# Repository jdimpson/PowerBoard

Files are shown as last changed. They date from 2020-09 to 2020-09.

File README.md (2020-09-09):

# PowerBoard Redux PCB

These are the Eage CAD Schematics and Board files, plus the Gerbers of some boards as-built, of an AdaFruit PowerBoost 1000C (https://www.adafruit.com/product/2465) adapted to the Raspberry Pi Zero form factor. It provides power to the +5VDC pins of the RPi header (protected via Schottkey diode). As AdaFruit describes the product this is based on, "With a built-in load-sharing battery charger circuit, you'll be able to keep your power-hungry project running even while recharging the battery!"

See also the PowerHolder board (https://github.com/jdimpson/PowerHolder) which is just like this one, but has battery clips to hold a Li Ion 18650 cell on the board, rather than fussing with JST connectors. It also provides a way to use a stock PowerBoost 10000C board so you don't have as much soldering to do.

The board patches the Low Battery (LBO) signal to the Pi via a level shifter, and also adds a programmable tactile button and LED.  You can use either one of those ubiquitous square tactile / momentary buttons, or one that mounts vertically (https://www.digikey.com/product-detail/en/te-connectivity-alcoswitch-switches/1825027-5/450-1662-ND/529484). The footprints for the two buttons overlap, which looks ugly and means you really can choose only one. It also provides a spot for a vertical slide switch that enables or disables the power circuit (https://www.digikey.com/product-detail/en/c-k/OS102011MA1QN1/CKN9559-ND/1981430). It's possible to find horizontal slide switch that fits in the same footprint. (I've only ordered them from ebay.)

Python software that works with the LBO signal, button, and LED are available in the [RPiIoT](https://github.com/jdimpson/RPiIoT) repo.

The MicroUSB connector is not the same foot print as AdaFruit uses in their PowerBoost, because I couldn't figure out which one it was. The part I use is an amphenol 10118194-0001LF (https://www.digikey.com/product-detail/en/amphenol-icc-fci/10118194-0001LF/609-4618-1-ND/2785382). It still has 4 through-hole-ish studs for strength (but can be hot-air reflowed) like AdaFruit's part, but the location of the studs are incompatible.

Battery is connected to a JST-style connector in a manner compatible with how AdaFruit does their polarity, or you can omit the connector and use the 2.54 mm pitch througholes to solder wires or a different connector to. Note that another Repo contains the PowerCarrier board, which is functionally identical to this board, but includes battery holders for a Li-Ion 18650 cell on the board.

Changelog
- Before v1.0 / Redux, I didn't know what I was doing, and kept laying out boards with traces that were way too small for the currents involved. 
- v1.01: Thickened VBAT, VLIPO, and USB traces from circuit to aux header; added zener diode to 5V trace into RPi; using VBAT rather than VLIPO in ENABLE pin switch. 

TODO:
- do over that preserve original PowerBoost footprint so that you can either reflow the board or just pop one of AdaFruit's board onto it. 

Raspberry Pi Pins used:

- GPIO17/Phy11 is connected to a momentary / tactile switch. Available for arbitrary software control (typically running my powerboard.py and associated code).
- GPIO27/Phy13 is connected to a resistor and then an LED. Available for arbitrary software control (e.g. flashing to show grace period, and typically running my powerboard.py and associated code).
- GPIO26/Phy37 is connected to via transistor and appropriate hold up resistor to the LBO signal of the PowerBoost circuit. This is how the Raspberry Pi knows to shut down. The signal is held at battery level (but level shifted to 3.3 V before hitting the RPi) until the Li Ion battery level drops below 3.4VDC (or maybe it's 3.2V, I forget) at which point the LBO signal drops to ground. This tells the software on the RPi to do a graceful shutdown.

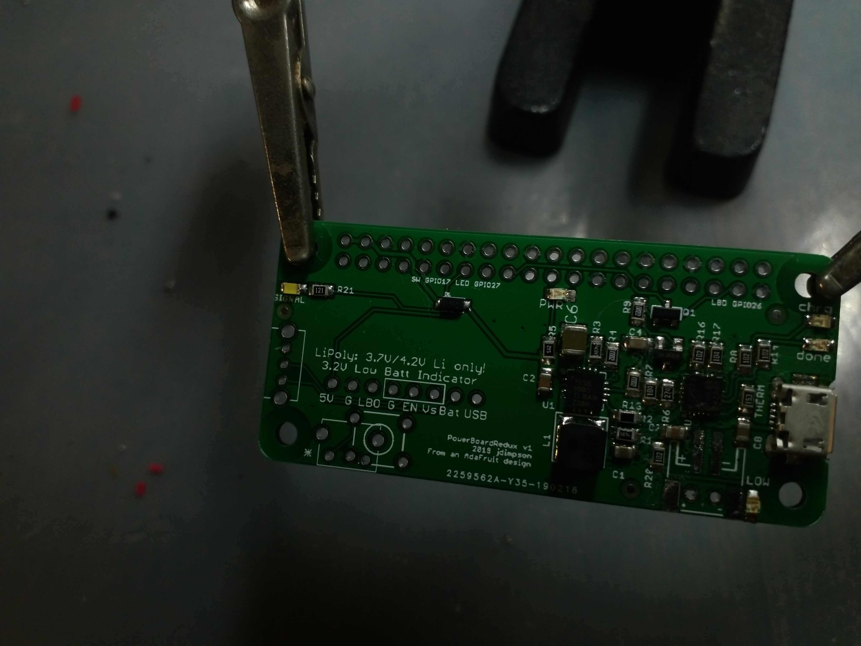
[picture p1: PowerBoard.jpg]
Image of powerboard


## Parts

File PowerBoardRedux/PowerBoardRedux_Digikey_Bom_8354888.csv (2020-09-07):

Manufacturer Part Number | Manufacturer | Digi-Key Part Number | Customer Reference | Reference Designator | Packaging | Part Status | Quantity | Unit Price | Extended Price | Quantity Available | Mfg Std Lead Time | Description | RoHS Status | Lead Free Status | REACH Status
ERA-6AEB102V | Panasonic Electronic Components | P1.0KDACT-ND | R8,R14,R16,R20 |  | Cut Tape (CT) | Active | 5 | 0.33000 | $1.65 | 116316 | 13 Weeks | RES 1K OHM 0.1% 1/8W 0805 | ROHS3 Compliant | Lead free | REACH Unaffected
ERJ-6ENF1874V | Panasonic Electronic Components | P1.87BTCT-ND | R1,R3 |  | Cut Tape (CT) | Active | 2 | 0.10000 | $0.20 | 8428 | 11 Weeks | RES SMD 1.87M OHM 1% 1/8W 0805 | ROHS3 Compliant | Lead free | REACH Unaffected
ERA-6AEB104V | Panasonic Electronic Components | P100KDACT-ND | R7,R17 |  | Cut Tape (CT) | Active | 2 | 0.33000 | $0.66 | 113947 | 13 Weeks | RES 100K OHM 0.1% 1/8W 0805 | ROHS3 Compliant | Lead free | REACH Unaffected
ERA-6AEB153V | Panasonic Electronic Components | P15KDACT-ND | THERM |  | Cut Tape (CT) | Active | 1 | 0.33000 | $0.33 | 71459 | 13 Weeks | RES 15K OHM 0.1% 1/8W 0805 | ROHS3 Compliant | Lead free | REACH Unaffected
ERJ-PB6B2003V | Panasonic Electronic Components | P20854CT-ND | R4,R13 |  | Cut Tape (CT) | Active | 2 | 0.35000 | $0.70 | 121 | 13 Weeks | RES SMD 200K OHM 0.1% 1/4W 0805 | ROHS3 Compliant | Lead free | Not Available
ERA-6AEB274V | Panasonic Electronic Components | P270KDACT-ND | R6 |  | Cut Tape (CT) | Active | 1 | 0.33000 | $0.33 | 18848 | 13 Weeks | RES 270K OHM 0.1% 1/8W 0805 | ROHS3 Compliant | Lead free | REACH Unaffected
ERA-6AEB3403V | Panasonic Electronic Components | P340KDACT-ND | R2 |  | Cut Tape (CT) | Active | 1 | 0.33000 | $0.33 | 12228 | 13 Weeks | RES 340K OHM 0.1% 1/8W 0805 | ROHS3 Compliant | Lead free | REACH Unaffected
C1210C107M8PACTU | KEMET | 399-11631-1-ND | C6 |  | Cut Tape (CT) | Active | 1 | 1.58000 | $1.58 | 36692 | 8 Weeks | CAP CER 100UF 10V X5R 1210 | ROHS3 Compliant | Lead free | REACH Unaffected
C0805C225M8RACTU | KEMET | 399-9208-1-ND | C2 |  | Cut Tape (CT) | Active | 1 | 0.30000 | $0.30 | 14731 | 28 Weeks | CAP CER 2.2UF 10V X7R 0805 | ROHS3 Compliant | Lead free | REACH Unaffected
VLS5045EX-6R8M | TDK Corporation | 445-174855-1-ND | L1 |  | Cut Tape (CT) | Active | 1 | 0.45000 | $0.45 | 4874 | 12 Weeks | FIXED IND 6.8UH 2.9A 59.8 MOHM | ROHS3 Compliant | Lead free | REACH Unaffected
APHCM2012VBC/D | Kingbright | 754-2118-1-ND | PWR |  | Cut Tape (CT) | Discontinued at Digi-Key | 1 | 0.56000 | $0.56 | 1312 | Not Available | LED BLUE CLEAR 2SMD | ROHS3 Compliant | Lead free | REACH Unaffected
APHCM2012ZGCK-F01 | Kingbright | 754-2120-1-ND | DONE |  | Cut Tape (CT) | Active | 1 | 0.52000 | $0.52 | 0 | 12 Weeks | LED GREEN CLEAR 2SMD | ROHS3 Compliant | Lead free | REACH Unaffected
APT2012SECK | Kingbright | 754-1130-1-ND | CHRG/LBO |  | Cut Tape (CT) | Active | 1 | 0.41000 | $0.41 | 11845 | 12 Weeks | LED ORANGE CLEAR CHIP SMD | ROHS3 Compliant | Lead free | REACH Unaffected
APT2012EC | Kingbright | 754-1128-1-ND | LOW |  | Cut Tape (CT) | Active | 1 | 0.39000 | $0.39 | 32882 | 12 Weeks | LED RED CLEAR CHIP SMD | ROHS3 Compliant | Lead free | REACH Unaffected
S2B-PH-SM4-TB(LF)(SN) | JST Sales America Inc. | 455-1749-1-ND | B1 |  | Cut Tape (CT) | Active | 1 | 0.58000 | $0.58 | 0 | 16 Weeks | CONN HEADER SMD R/A 2POS 2MM | ROHS3 Compliant | Lead free | REACH Unaffected
MCP73871-2AAI/ML | Microchip Technology | MCP73871-2AAI/ML-ND | U2 |  | Tube | Active | 1 | 1.79000 | $1.79 | 2086 | 6 Weeks | IC USB/AC BATT CHRGR W/PPM 20QFN | ROHS3 Compliant | Lead free | REACH Unaffected
MMUN2133LT1G | ON Semiconductor | MMUN2133LT1GOSCT-ND | T1 |  | Cut Tape (CT) | Active | 1 | 0.12000 | $0.12 | 13716 | 4 Weeks | TRANS PREBIAS PNP 246MW SOT23-3 | ROHS3 Compliant | Lead free | REACH Unaffected
10118194-0001LF | Amphenol ICC (FCI) | 609-4618-1-ND | CN1 |  | Cut Tape (CT) | Active | 1 | 0.43000 | $0.43 | 26794 | 12 Weeks | CONN RCPT USB2.0 MICRO B SMD R/A | RoHS Compliant | Lead free | REACH Unaffected
TPS61090RSAR | Texas Instruments | 296-15259-1-ND | U1 |  | Cut Tape (CT) | Active | 1 | 2.34000 | $2.34 | 8334 | 6 Weeks | IC REG BOOST ADJUSTABLE 2A 16QFN | ROHS3 Compliant | Lead free | REACH Unaffected
ERA-6AEB121V | Panasonic Electronic Components | P120DACT-ND | R21 |  | Cut Tape (CT) | Active | 1 | 0.33000 | $0.33 | 19434 | 13 Weeks | RES 120 OHM 0.1% 1/8W 0805 | ROHS3 Compliant | Lead free | REACH Unaffected
ERJ-PB6B2200V | Panasonic Electronic Components | P20516CT-ND | R9 |  | Cut Tape (CT) | Active | 1 | 0.35000 | $0.35 | 9013 | 13 Weeks | RES SMD 220 OHM 0.1% 1/4W 0805 | ROHS3 Compliant | Lead free | Not Available
BSS138LT1G | ON Semiconductor | BSS138LT1GOSCT-ND | Q1 |  | Cut Tape (CT) | Active | 1 | 0.25000 | $0.25 | 944594 | 6 Weeks | MOSFET N-CH 50V 200MA SOT-23 | ROHS3 Compliant | Lead free | REACH Unaffected
ERJ-P06J512V | Panasonic Electronic Components | P5.1KADCT-ND | R5 |  | Cut Tape (CT) | Active | 1 | 0.11000 | $0.11 | 19640 | 13 Weeks | RES SMD 5.1K OHM 5% 1/2W 0805 | ROHS3 Compliant | Lead free | REACH Unaffected
CL21A106KPCLQNC | Samsung Electro-Mechanics | 1276-2402-1-ND | C1,C7,C8 |  | Cut Tape (CT) | Active | 3 | 0.14000 | $0.42 | 2656226 | 22 Weeks | CAP CER 10UF 10V X5R 0805 | ROHS3 Compliant | Lead free | REACH Unaffected
NRVTS245ESFT3G | ON Semiconductor | NRVTS245ESFT3GOSCT-ND | D1 |  | Cut Tape (CT) | Active | 1 | 0.33000 | $0.33 | 8249 | 10 Weeks | DIODE SCHOTTKY 45V 2A SOD123FL | ROHS3 Compliant | Lead free | REACH Unaffected
C0805C104K8RACTU | KEMET | 399-7999-1-ND | C4 |  | Cut Tape (CT) | Active | 1 | 0.20000 | $0.20 | 62964 | 8 Weeks | CAP CER 0.1UF 10V X7R 0805 | ROHS3 Compliant | Lead free | REACH Unaffected
IN-S85AT5UW | Inolux | 1830-1080-1-ND | SIGNAL |  | Cut Tape (CT) | Active | 1 | 0.43000 | $0.43 | 1348 | 5 Weeks | LED WHITE CLEAR 0805 SMD | ROHS3 Compliant | Lead free | Not Available
1825027-5 | TE Connectivity ALCOSWITCH Switches | 450-1662-ND | SW1 |  | Bulk | Active | 1 | 0.18000 | $0.18 | 51762 | 15 Weeks | SWITCH TACTILE SPST-NO 0.05A 24V | RoHS Compliant | Lead free | Not Available
OS102011MA1QN1 | C&K | CKN9559-ND | SW2 |  | Bulk | Active | 1 | 0.48000 | $0.48 | 61411 | 24 Weeks | SWITCH SLIDE SPDT 100MA 12V | ROHS3 Compliant | Lead free | REACH Unaffected

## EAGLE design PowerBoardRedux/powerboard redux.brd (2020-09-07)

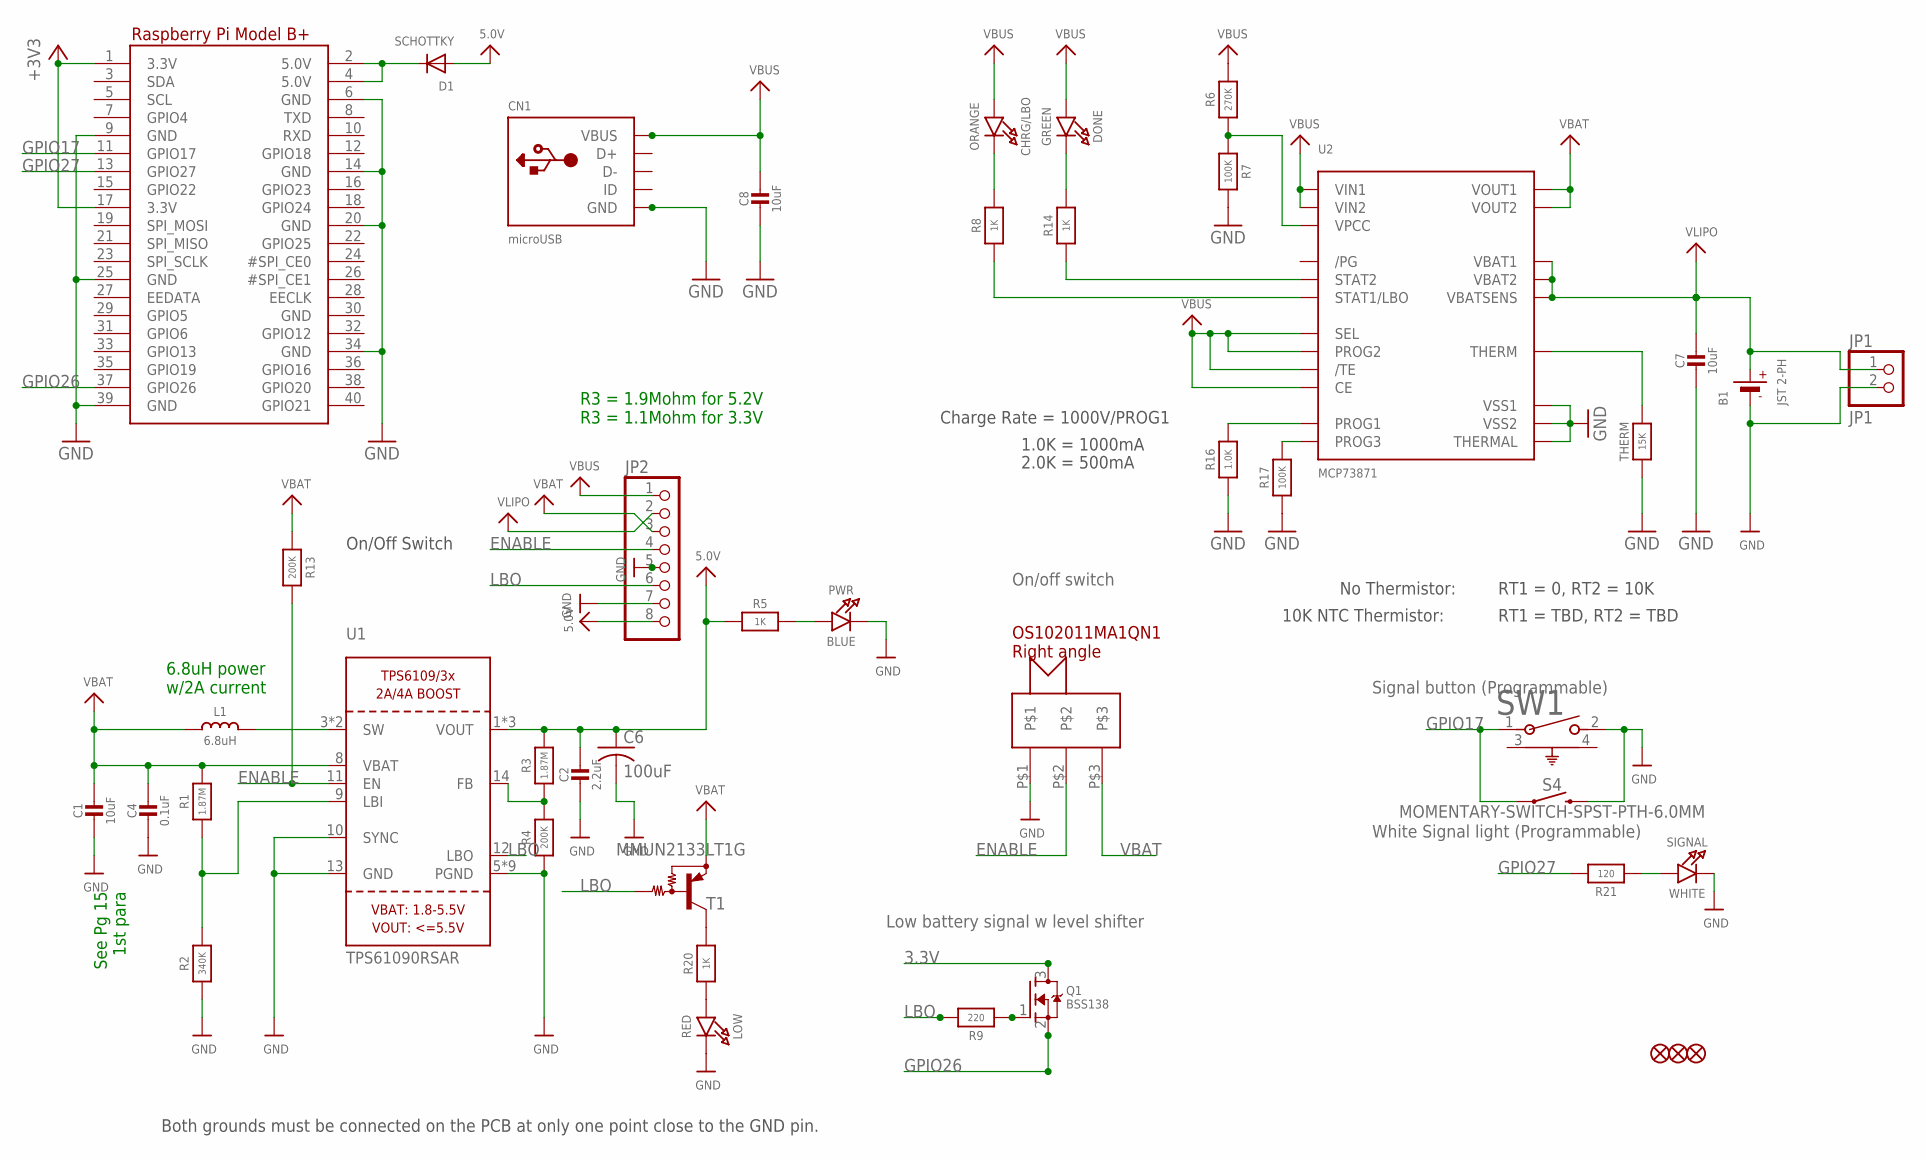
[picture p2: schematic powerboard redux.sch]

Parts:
B1: JST 2-PH; JSTPH2
C1, C7, C8: 10uF; 0805-NO@1
C2: 2.2uF; 0805-NO@1
C4: 0.1uF; 0805_10MGAP
C6: 100uF; C1210
CHRG/LBO: ORANGE; CHIPLED_0805_NOOUTLINE
CN1: microUSB; 4UCONN_20329
D1: SCHOTTKY; SOD-123FL
DONE: GREEN; CHIPLED_0805_NOOUTLINE
FID1, FID2, FID3: FIDUCIAL""; FIDUCIAL_1MM
JP1: JP1; 1X02_ROUND
JP2: HEADER-1X8ROUND; 1X08_ROUND
L1: 6.8uH; INDUCTOR_5X5MM_TDK_VLC5045
LOW: RED; CHIPLED_0805_NOOUTLINE
PWR: BLUE; CHIPLED_0805_NOOUTLINE
Q1: BSS138; SOT23-R
R1: 1.87M; _0805MP
R2: 340K; _0805MP
R3: 1.87M; 0805-NO
R4, R13: 200K; 0805-NO
R5, R8, R14, R20: 1K; 0805-NO
R6: 270K; 0805-NO
R7, R17: 100K; 0805-NO
R9: 220; 0805-NO
R16: 1.0K; 0805-NO
R21: 120; 0805-NO
RPI1: RASPBERRYPI_BPLUS_BONNETNODIM; PI_BONNET_NODIM
S4: MOMENTARY-SWITCH-SPST-PTH-6.0MM; TACTILE_SWITCH_PTH_6.0MM
SIGNAL: WHITE; CHIPLED_0805_NOOUTLINE
SW1: 1825027-5; SW2_1825027-A
SW2: OS102011MA1QN1
T1: MMUN2133LT1G; SC59-BEC
THERM: 15K; 0805-NO
U1: TPS61090RSAR; PVQFN-16
U2: MCP73871; QFN20_4MM

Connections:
3.3V: Q1.3 (D), RPI1.1 (3.3V), RPI1.17 (3.3V)
5.0V: C2.1, C6.1, D1.A, JP2.8, R3.2, R5.1, U1.1 (VOUT), U1.15 (VOUT), U1.16 (VOUT)
5.0V@1: D1.C, RPI1.2 (5.0V), RPI1.4 (5.0V)
ENABLE: JP2.4, R13.2, SW2.P$2, U1.11 (EN)
GND: B1.1 (-), C1.2, C2.2, C4.2, C6.2, C7.2, C8.2, CN1.BASE@1 (GND), CN1.BASE@2 (GND), CN1.GND, CN1.SPRT@1 (GND), CN1.SPRT@2 (GND), CN1.SPRT@3 (GND), CN1.SPRT@4 (GND), JP1.2, JP2.5, JP2.7, LOW.C, PWR.C, R2.1, R4.1, R7.2, R16.1, R17.1, RPI1.6 (GND), RPI1.9 (GND), RPI1.14 (GND), RPI1.20 (GND), RPI1.25 (GND), RPI1.30 (GND), RPI1.34 (GND), RPI1.39 (GND), S4.3 (2), SIGNAL.C, SW1.2, SW2.P$1, THERM.1, U1.5 (PGND), U1.6 (PGND), U1.7 (PGND), U1.10 (SYNC), U1.13 (GND), U1.P$18 (PGND), U1.P$19 (PGND), U1.P$20 (PGND), U1.P$21 (PGND), U1.P$22 (PGND), U1.THERMAL (PGND), U2.P$10 (VSS1), U2.P$11 (VSS2), U2.P$21 (THERMAL)
GPIO17: RPI1.11 (GPIO17), S4.1, SW1.1
GPIO26: Q1.2 (S), RPI1.37 (GPIO26)
GPIO27: R21.2, RPI1.13 (GPIO27)
LBO: JP2.6, R9.2, T1.B, U1.12 (LBO)
unnamed: L1.P$2 (2), U1.3 (SW), U1.4 (SW)
unnamed: LOW.A, R20.1
unnamed: R1.1, R2.2, U1.9 (LBI)
unnamed: PWR.A, R5.2
unnamed: R3.1, R4.2, U1.14 (FB)
unnamed: R20.2, T1.C
unnamed: R6.1, R7.1, U2.P$2 (VPCC)
unnamed: DONE.C, R14.2
unnamed: R14.1, U2.P$7 (STAT2)
unnamed: THERM.2, U2.P$5 (THERM)
unnamed: R8.1, U2.P$8 (STAT1/LBO)
unnamed: CHRG/LBO.C, R8.2
unnamed: R17.2, U2.P$12 (PROG3)
unnamed: Q1.1 (G), R9.1
unnamed: R21.1, SIGNAL.A
unnamed: R16.2, U2.P$13 (PROG1)
VBAT: C1.1, C4.1, JP2.3, L1.P$1 (1), R1.2, R13.1, SW2.P$3, T1.E, U1.8 (VBAT), U2.P$1 (VOUT1), U2.P$20 (VOUT2)
VBUS: C8.1, CHRG/LBO.A, CN1.VBUS, DONE.A, JP2.1, R6.2, U2.P$3 (SEL), U2.P$4 (PROG2), U2.P$9 (/TE), U2.P$17 (CE), U2.P$18 (VIN1), U2.P$19 (VIN2)
VLIPO: B1.2 (+), C7.1, JP1.1, JP2.2, U2.P$14 (VBAT1), U2.P$15 (VBAT2), U2.P$16 (VBATSENS)

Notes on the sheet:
Both grounds must be connected on the PCB at only one point close to the GND pin.
On/Off Switch
See Pg 15 1st para
6.8uH power w/2A current
R3 = 1.9Mohm for 5.2V R3 = 1.1Mohm for 3.3V
Charge Rate = 1000V/PROG1
1.0K = 1000mA
2.0K = 500mA
No Thermistor:
10K NTC Thermistor:
RT1 = 0, RT2 = 10K
RT1 = TBD, RT2 = TBD
Low battery signal w level shifter
On/off switch
Signal button (Programmable)
White Signal light (Programmable)

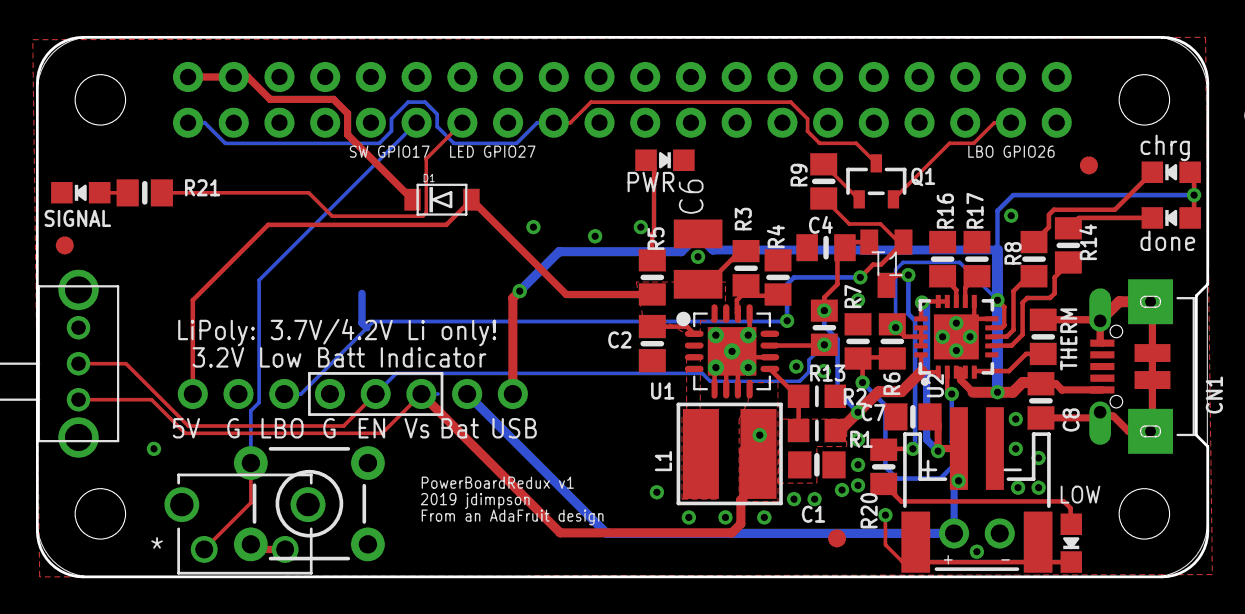
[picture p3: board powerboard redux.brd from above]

Board: 2 copper layers, 65.0 x 30.0 mm, 44 parts (0 on the bottom side), 28 nets.

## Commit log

2020-09-07 Fixed typo ref to Adafruit's powerboost
2020-09-07 Described battery attachment
2020-09-07 Managed to make board & schematic inconsistent, fixed
    [powerboard redux.brd, powerboard redux.sch]
2020-09-07 Cleanup for BOM upload
    [PowerBoardRedux_Digikey_Bom_8354888.csv, powerboard redux.brd, powerboard redux.sch]
2020-09-07 Refernce to PowerHolder

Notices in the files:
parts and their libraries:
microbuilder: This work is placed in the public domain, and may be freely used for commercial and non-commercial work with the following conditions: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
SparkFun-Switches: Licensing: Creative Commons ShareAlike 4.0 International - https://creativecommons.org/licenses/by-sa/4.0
